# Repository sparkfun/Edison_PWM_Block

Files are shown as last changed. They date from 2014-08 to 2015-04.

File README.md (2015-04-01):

SparkFun Edison PWM Block
==================================================

SparkFun Edison PWM Block

[*SparkFun Edison PWM Block(DEV-13042)*](https://www.sparkfun.com/products/13042)

This card adds eight channels of PWM control to the Edison's I<sup>2</sup>C bus. While the PWM output can be used for any generic PWM application, it is specifically intended to provide drive control for up to eight standard hobby-type servo motors. To that end, it has an independent input for supply voltage for the servos above the normal range of the Edison, and 8 connections that support the most common pinout of hobby servo motors.

The PCA9685 provides open-collector or push-pull output capabilities; as the intended target is servo motors, the board has a pull-up resistor to the independently connected servo supply voltage. The PCA9685 has an independent clock that can be operated at 50Hz, for servo control; at that frequency, the 12-bit resolution of the device provides approximately 200 steps of resolution for a servo motor.

The PCA9685 can be used as an open collector current driver for LEDs up to 25mA as well. Six solder jumpers allow the user to attach up to 63 of these cards to a single Edison, or to adjust the address of the PCA9685 to avoid collision with other addresses on the bus.

Repository Contents
-------------------
* **/Hardware** - All Eagle design files (.brd, .sch)
* **/Production** - Test bed files and production panel files

License Information
-------------------
The hardware is released under [Creative Commons ShareAlike 4.0 International](https://creativecommons.org/licenses/by-sa/4.0/).
The code is beerware; if you see me (or any other SparkFun employee) at the local, and you've found our code helpful, please buy us a round!

Distributed as-is; no warranty is given.

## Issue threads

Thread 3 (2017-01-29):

I2C not Working

Luchta, 2017-01-29:
I got the following error code after trying to get the sample code to work:

"terminate called after throwing an instance of 'std::invalid_argument'
what(): Unknown error in I2c::readReg()"

I found the Error in the Constructor of pca9685.
Fabulous Idea to set the prescaler and let it read registers, before setting the address.
changing the order of those two fixed the error.

mhord, 2017-01-30:
Please provide more information. There's no code at all in this repository, and the constructor for the pca9685 class in the library we wrote for the block doesn't access anything before setting the address. I'm looking at [this repository](https://github.com/sparkfun/SparkFun_PWM_Block_for_Edison_CPP_Library) for the code. Is there a code example elsewhere that doesn't initialize things in the right order?

Luchta, 2017-01-30:
Hey there,

I am talking about this part:

// Constructor. Pretty self explanatory.
pca9685::pca9685(mraa::I2c* pca_port, uint8_t myI2CAddress):
   _pca_port(pca_port), _myAddress(myI2CAddress),
   _minServoPL(MIN_WIDTH), _maxServoPL(MAX_WIDTH),
   _minAngle(0), _maxAngle(180)
{
   setPrescaler(14); // f= ~400Hz
   _pca_port->address(_myAddress);
   _pca_port->writeReg(MODE1, AI); //enable autoincrement and osc
   _pca_port->writeReg(MODE2, INVRT); // open drain outs
}

the address is written in "_pca_port->address(_myAddress);"

however, "setPrescaler(14);" already accesses the bus and created the
error I mentioned.

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

mhord, 2017-01-30:
Got it. Thanks for the tip!

Closed 2017-01-30.

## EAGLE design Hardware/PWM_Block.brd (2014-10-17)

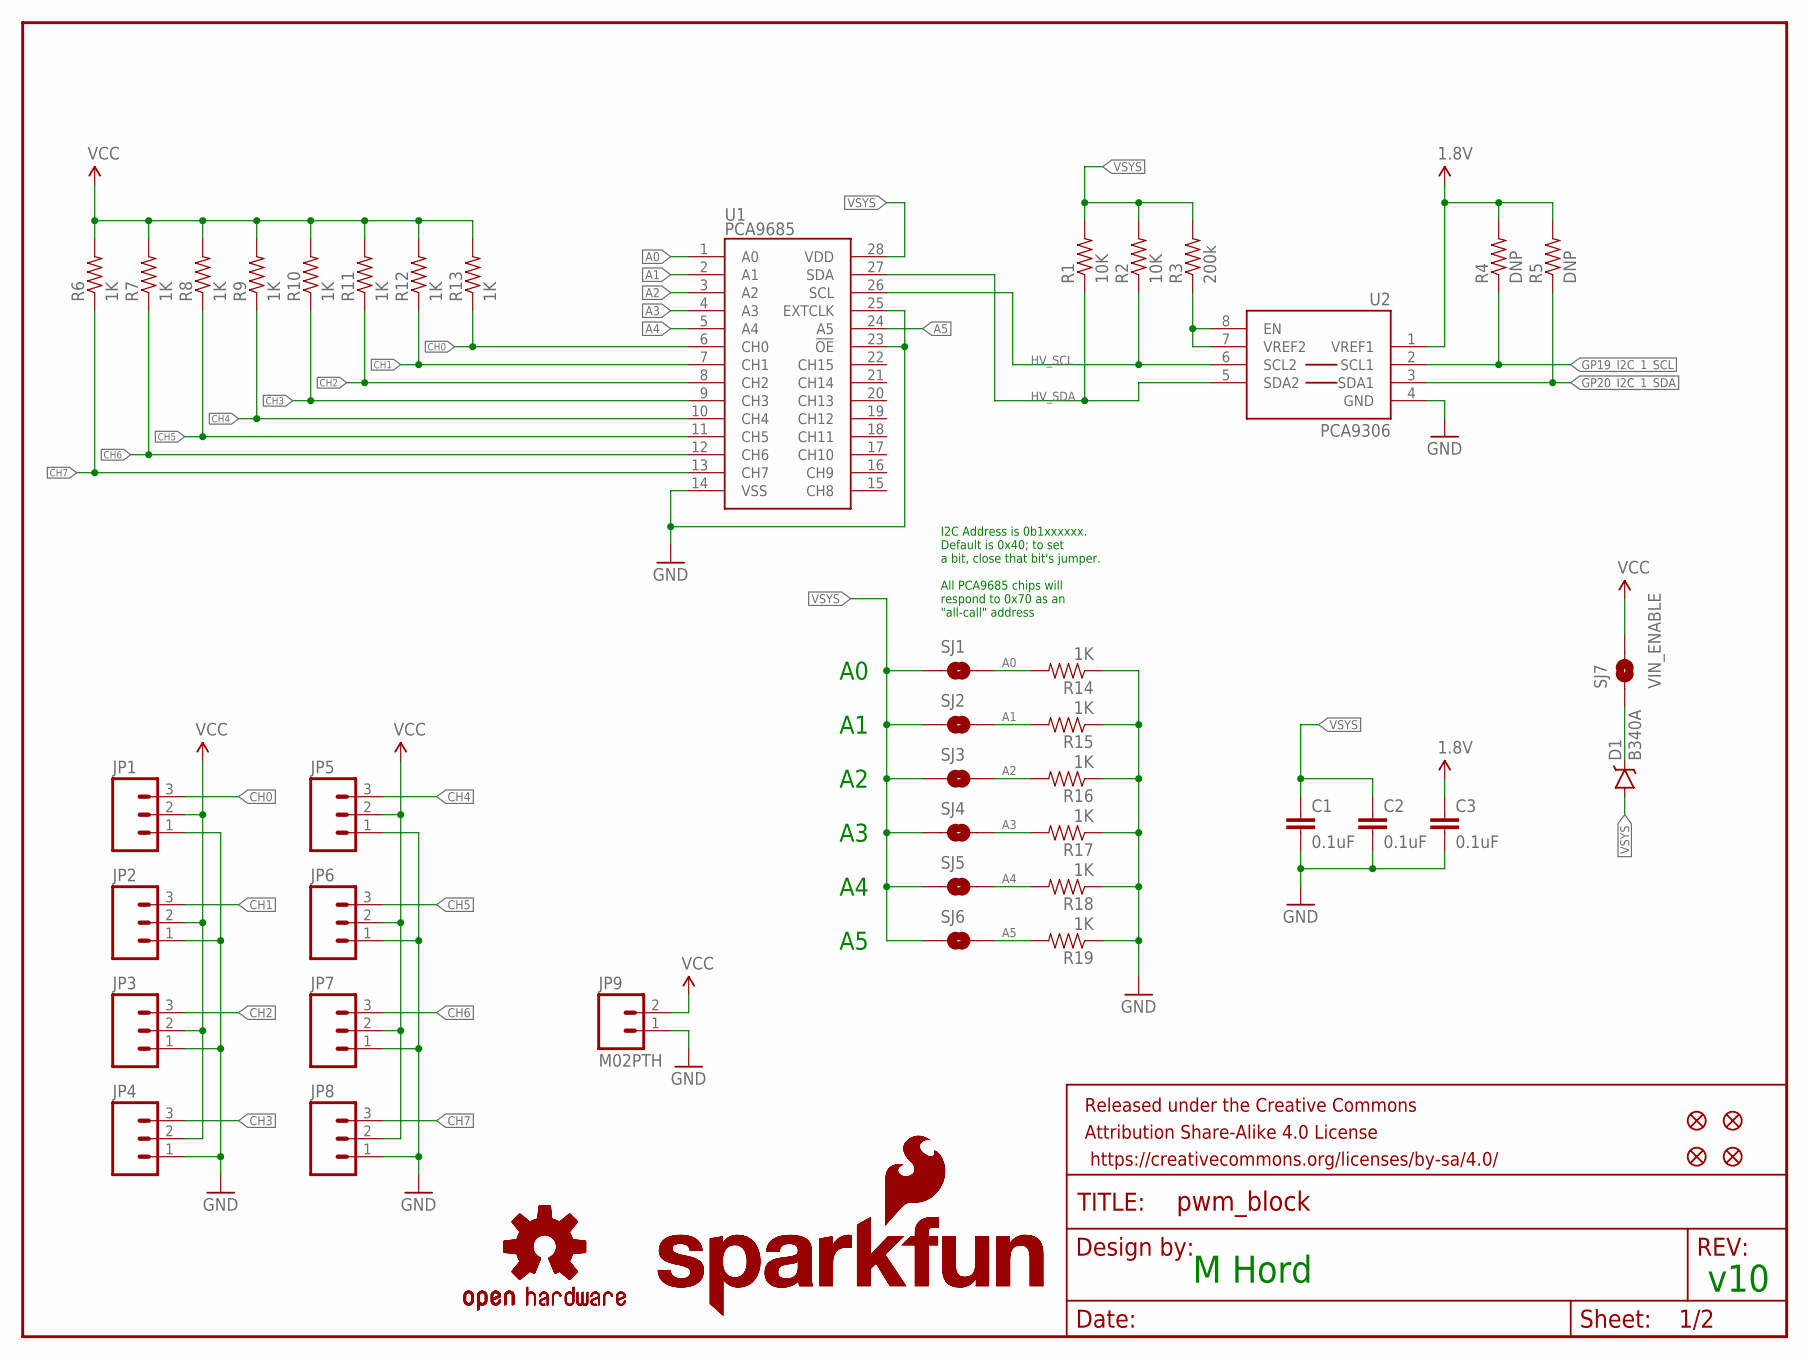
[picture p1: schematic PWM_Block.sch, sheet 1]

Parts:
C1, C2, C3: 0.1uF; 0603-CAP
D1: B340A; SMA-DIODE
FID1, FID2, FID3, FID4: FIDUCIAL1X2; FIDUCIAL-1X2
FRAME1: FRAME-LETTER; CREATIVE_COMMONS
JP1, JP2, JP3, JP4, JP5, JP6, JP7, JP8: M03PTH; 1X03
JP9: M02PTH; 1X02
LOGO1, LOGO3: SFE_LOGO_NAME_FLAME.1_INCH; SFE_LOGO_NAME_FLAME_.1
LOGO2, LOGO4: OSHW-LOGOS; OSHW-LOGO-S
R1, R2: 10K; 0603-RES
R3: 200k; 0603-RES
R4, R5: DNP; 0603-RES
R6, R7, R8, R9, R10, R11, R12, R13, R14, R15, R16, R17, R18, R19: 1K; 0603-RES
SJ1, SJ2, SJ3, SJ4, SJ5, SJ6: JUMPER-PAD-2-NOYES_SILK; PAD-JUMPER-2-NO_YES_SILK
SJ7: VIN_ENABLE; PAD-JUMPER-2-NO_YES_SILK
U1: PCA9685; TSSOP-28_4MM
U2: PCA9306; PCA9306DC-1:1

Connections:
1.8V: C3.1, R4.2, R5.2, U2.1 (VREF1); also elsewhere on the board
A0: R14.2, SJ1.2, U1.1 (A0)
A1: R15.2, SJ2.2, U1.2 (A1)
A2: R16.2, SJ3.2, U1.3 (A2)
A3: R17.2, SJ4.2, U1.4 (A3)
A4: R18.2, SJ5.2, U1.5 (A4)
A5: R19.2, SJ6.2, U1.24 (A5)
CH0: JP1.3, R13.1, U1.6 (CH0)
CH1: JP2.3, R12.1, U1.7 (CH1)
CH2: JP3.3, R11.1, U1.8 (CH2)
CH3: JP4.3, R10.1, U1.9 (CH3)
CH4: JP5.3, R9.1, U1.10 (CH4)
CH5: JP6.3, R8.1, U1.11 (CH5)
CH6: JP7.3, R7.1, U1.12 (CH6)
CH7: JP8.3, R6.1, U1.13 (CH7)
GND: C1.2, C2.2, C3.2, JP1.1, JP2.1, JP3.1, JP4.1, JP5.1, JP6.1, JP7.1, JP8.1, JP9.1, R14.1, R15.1, R16.1, R17.1, R18.1, R19.1, U1.14 (VSS), U1.23 (!OE), U1.25 (EXTCLK), U2.4 (GND); also elsewhere on the board
GP19_I2C_1_SCL: R4.1, U2.2 (SCL1); also elsewhere on the board
GP20_I2C_1_SDA: R5.1, U2.3 (SDA1); also elsewhere on the board
HV_SCL: R2.1, U1.26 (SCL), U2.6 (SCL2)
HV_SDA: R1.1, U1.27 (SDA), U2.5 (SDA2)
unnamed: R3.1, U2.7 (VREF2), U2.8 (EN)
unnamed: D1.C, SJ7.1
VCC: JP1.2, JP2.2, JP3.2, JP4.2, JP5.2, JP6.2, JP7.2, JP8.2, JP9.2, R6.2, R7.2, R8.2, R9.2, R10.2, R11.2, R12.2, R13.2, SJ7.2
VSYS: C1.1, C2.1, D1.A, R1.2, R2.2, R3.2, SJ1.1, SJ2.1, SJ3.1, SJ4.1, SJ5.1, SJ6.1, U1.28 (VDD); also elsewhere on the board

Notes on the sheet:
M Hord
v10
I2C Address is 0b1xxxxxx. Default is 0x40; to set a bit, close that bit's jumper. All PCA9685 chips will respond to 0x70 as an "all-call" address

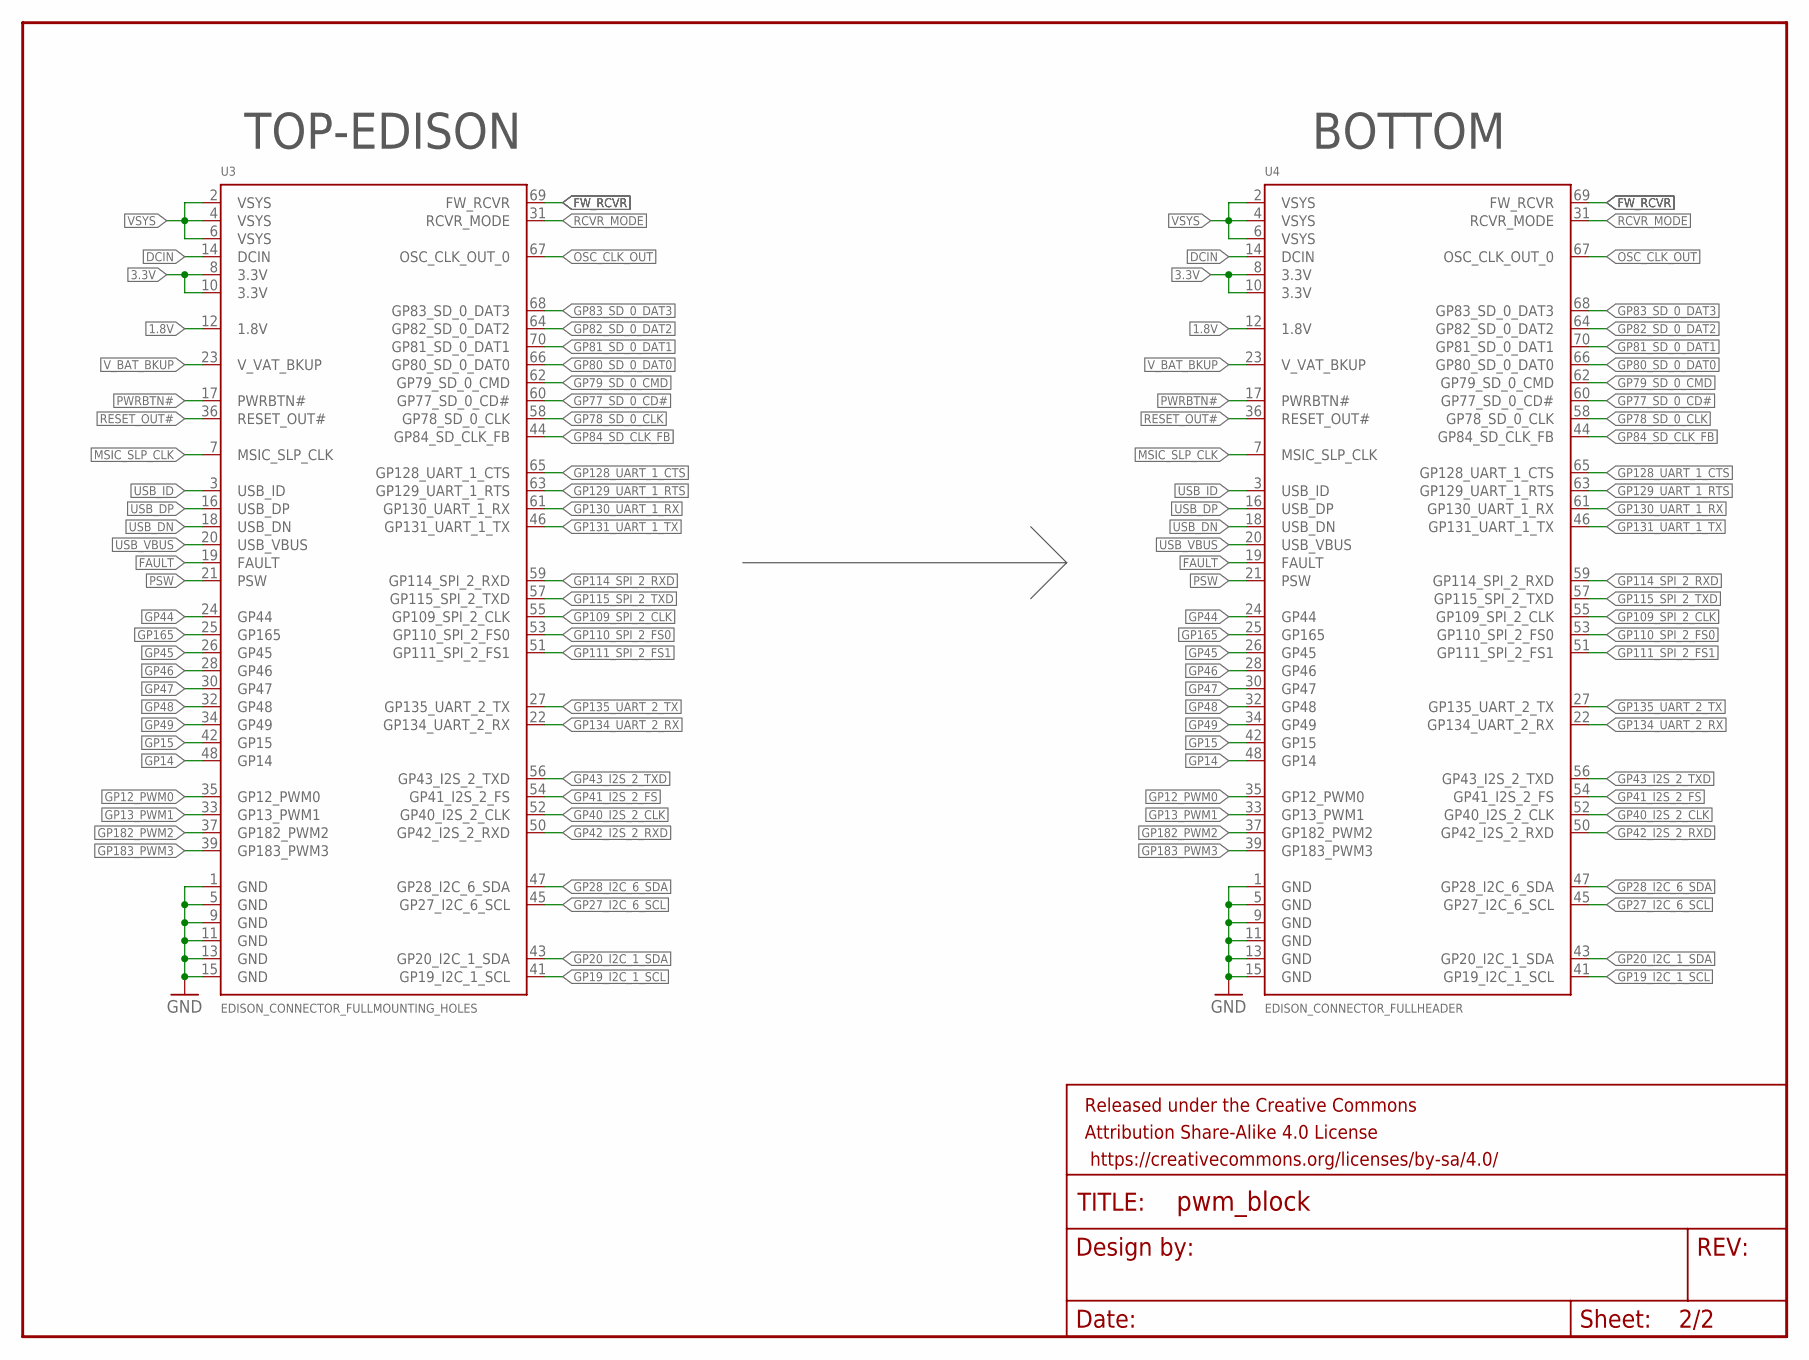
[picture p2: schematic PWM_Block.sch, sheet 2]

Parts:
FRAME2: FRAME-LETTER; CREATIVE_COMMONS
U3: EDISON_CONNECTOR_FULLMOUNTING_HOLES; EDISON_DAUGHTER
U4: EDISON_CONNECTOR_FULLHEADER; DF40C-70DP-0.4(51)

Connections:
1.8V: U3.12 (1.8V), U4.12 (1.8V); also elsewhere on the board
3.3V: U3.8 (3.3V), U3.10 (3.3V), U4.8 (3.3V), U4.10 (3.3V)
DCIN: U3.14 (DCIN), U4.14 (DCIN)
FAULT: U3.19 (FAULT), U4.19 (FAULT)
FW_RCVR: U3.69 (FW_RCVR), U4.69 (FW_RCVR)
GND: U3.1 (GND), U3.5 (GND), U3.9 (GND), U3.11 (GND), U3.13 (GND), U3.15 (GND), U4.1 (GND), U4.5 (GND), U4.9 (GND), U4.11 (GND), U4.13 (GND), U4.15 (GND); also elsewhere on the board
GP12_PWM0: U3.35 (GP12_PWM0), U4.35 (GP12_PWM0)
GP13_PWM1: U3.33 (GP13_PWM1), U4.33 (GP13_PWM1)
GP14: U3.48 (GP14), U4.48 (GP14)
GP15: U3.42 (GP15), U4.42 (GP15)
GP19_I2C_1_SCL: U3.41 (GP19_I2C_1_SCL), U4.41 (GP19_I2C_1_SCL); also elsewhere on the board
GP20_I2C_1_SDA: U3.43 (GP20_I2C_1_SDA), U4.43 (GP20_I2C_1_SDA); also elsewhere on the board
GP27_I2C_6_SCL: U3.45 (GP27_I2C_6_SCL), U4.45 (GP27_I2C_6_SCL)
GP28_I2C_6_SDA: U3.47 (GP28_I2C_6_SDA), U4.47 (GP28_I2C_6_SDA)
GP40_I2S_2_CLK: U3.52 (GP40_I2S_2_CLK), U4.52 (GP40_I2S_2_CLK)
GP41_I2S_2_FS: U3.54 (GP41_I2S_2_FS), U4.54 (GP41_I2S_2_FS)
GP42_I2S_2_RXD: U3.50 (GP42_I2S_2_RXD), U4.50 (GP42_I2S_2_RXD)
GP43_I2S_2_TXD: U3.56 (GP43_I2S_2_TXD), U4.56 (GP43_I2S_2_TXD)
GP44: U3.24 (GP44), U4.24 (GP44)
GP45: U3.26 (GP45), U4.26 (GP45)
GP46: U3.28 (GP46), U4.28 (GP46)
GP47: U3.30 (GP47), U4.30 (GP47)
GP48: U3.32 (GP48), U4.32 (GP48)
GP49: U3.34 (GP49), U4.34 (GP49)
GP77_SD_0_CD#: U3.60 (GP77_SD_0_CD#), U4.60 (GP77_SD_0_CD#)
GP78_SD_0_CLK: U3.58 (GP78_SD_0_CLK), U4.58 (GP78_SD_0_CLK)
GP79_SD_0_CMD: U3.62 (GP79_SD_0_CMD), U4.62 (GP79_SD_0_CMD)
GP80_SD_0_DAT0: U3.66 (GP80_SD_0_DAT0), U4.66 (GP80_SD_0_DAT0)
GP81_SD_0_DAT1: U3.70 (GP81_SD_0_DAT1), U4.70 (GP81_SD_0_DAT1)
GP82_SD_0_DAT2: U3.64 (GP82_SD_0_DAT2), U4.64 (GP82_SD_0_DAT2)
GP83_SD_0_DAT3: U3.68 (GP83_SD_0_DAT3), U4.68 (GP83_SD_0_DAT3)
GP84_SD_CLK_FB: U3.44 (GP84_SD_CLK_FB), U4.44 (GP84_SD_CLK_FB)
GP109_SPI_2_CLK: U3.55 (GP109_SPI_2_CLK), U4.55 (GP109_SPI_2_CLK)
GP110_SPI_2_FS0: U3.53 (GP110_SPI_2_FS0), U4.53 (GP110_SPI_2_FS0)
GP111_SPI_2_FS1: U3.51 (GP111_SPI_2_FS1), U4.51 (GP111_SPI_2_FS1)
GP114_SPI_2_RXD: U3.59 (GP114_SPI_2_RXD), U4.59 (GP114_SPI_2_RXD)
GP115_SPI_2_TXD: U3.57 (GP115_SPI_2_TXD), U4.57 (GP115_SPI_2_TXD)
GP128_UART_1_CTS: U3.65 (GP128_UART_1_CTS), U4.65 (GP128_UART_1_CTS)
GP129_UART_1_RTS: U3.63 (GP129_UART_1_RTS), U4.63 (GP129_UART_1_RTS)
GP130_UART_1_RX: U3.61 (GP130_UART_1_RX), U4.61 (GP130_UART_1_RX)
GP131_UART_1_TX: U3.46 (GP131_UART_1_TX), U4.46 (GP131_UART_1_TX)
GP134_UART_2_RX: U3.22 (GP134_UART_2_RX), U4.22 (GP134_UART_2_RX)
GP135_UART_2_TX: U3.27 (GP135_UART_2_TX), U4.27 (GP135_UART_2_TX)
GP165: U3.25 (GP165), U4.25 (GP165)
GP182_PWM2: U3.37 (GP182_PWM2), U4.37 (GP182_PWM2)
GP183_PWM3: U3.39 (GP183_PWM3), U4.39 (GP183_PWM3)
MSIC_SLP_CLK: U3.7 (MSIC_SLP_CLK), U4.7 (MSIC_SLP_CLK)
OSC_CLK_OUT: U3.67 (OSC_CLK_OUT_0), U4.67 (OSC_CLK_OUT_0)
PSW: U3.21 (PSW), U4.21 (PSW)
PWRBTN#: U3.17 (PWRBTN#), U4.17 (PWRBTN#)
RCVR_MODE: U3.31 (RCVR_MODE), U4.31 (RCVR_MODE)
RESET_OUT#: U3.36 (RESET_OUT#), U4.36 (RESET_OUT#)
USB_DN: U3.18 (USB_DN), U4.18 (USB_DN)
USB_DP: U3.16 (USB_DP), U4.16 (USB_DP)
USB_ID: U3.3 (USB_ID), U4.3 (USB_ID)
USB_VBUS: U3.20 (USB_VBUS), U4.20 (USB_VBUS)
VSYS: U3.2 (VSYS), U3.4 (VSYS), U3.6 (VSYS), U4.2 (VSYS), U4.4 (VSYS), U4.6 (VSYS); also elsewhere on the board
V_BAT_BKUP: U3.23 (V_VAT_BKUP), U4.23 (V_VAT_BKUP)

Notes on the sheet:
TOP-EDISON
BOTTOM

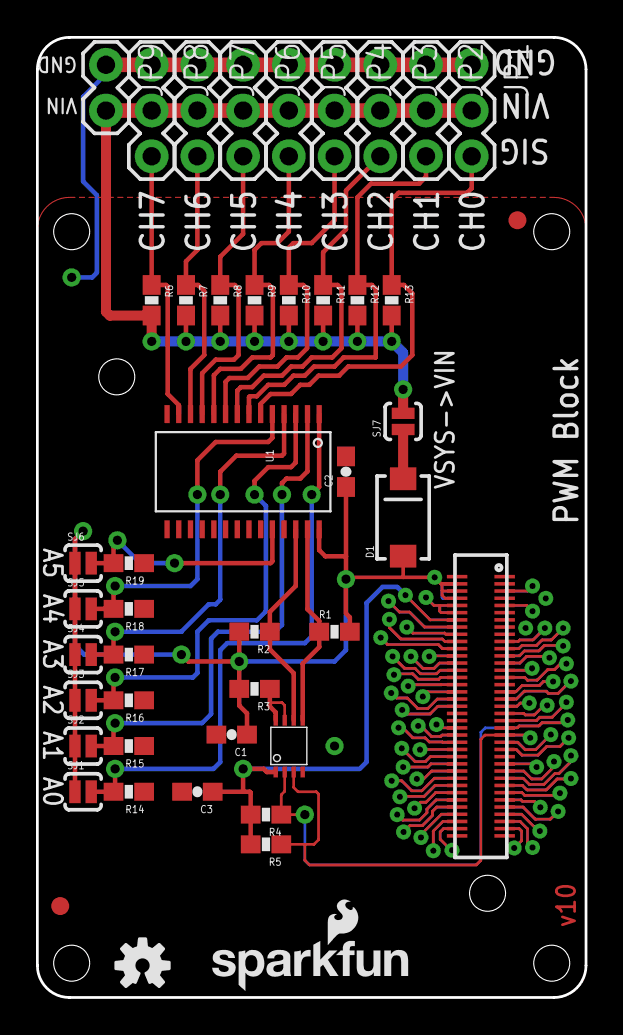
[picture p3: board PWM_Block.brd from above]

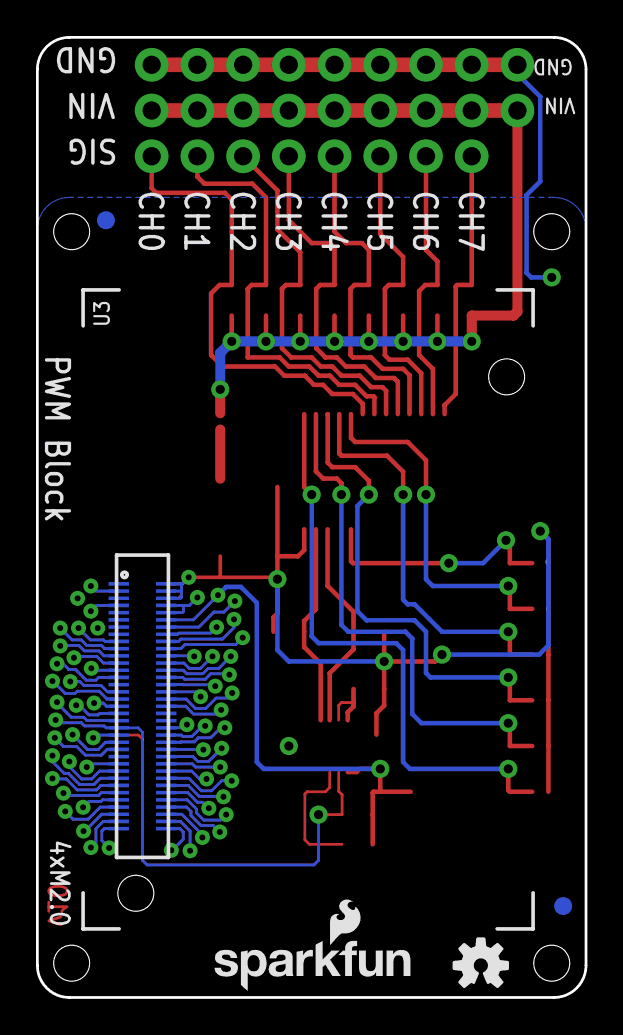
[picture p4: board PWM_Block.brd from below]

Board: 2 copper layers, 30.5 x 53.3 mm, 53 parts (6 on the bottom side), 77 nets.

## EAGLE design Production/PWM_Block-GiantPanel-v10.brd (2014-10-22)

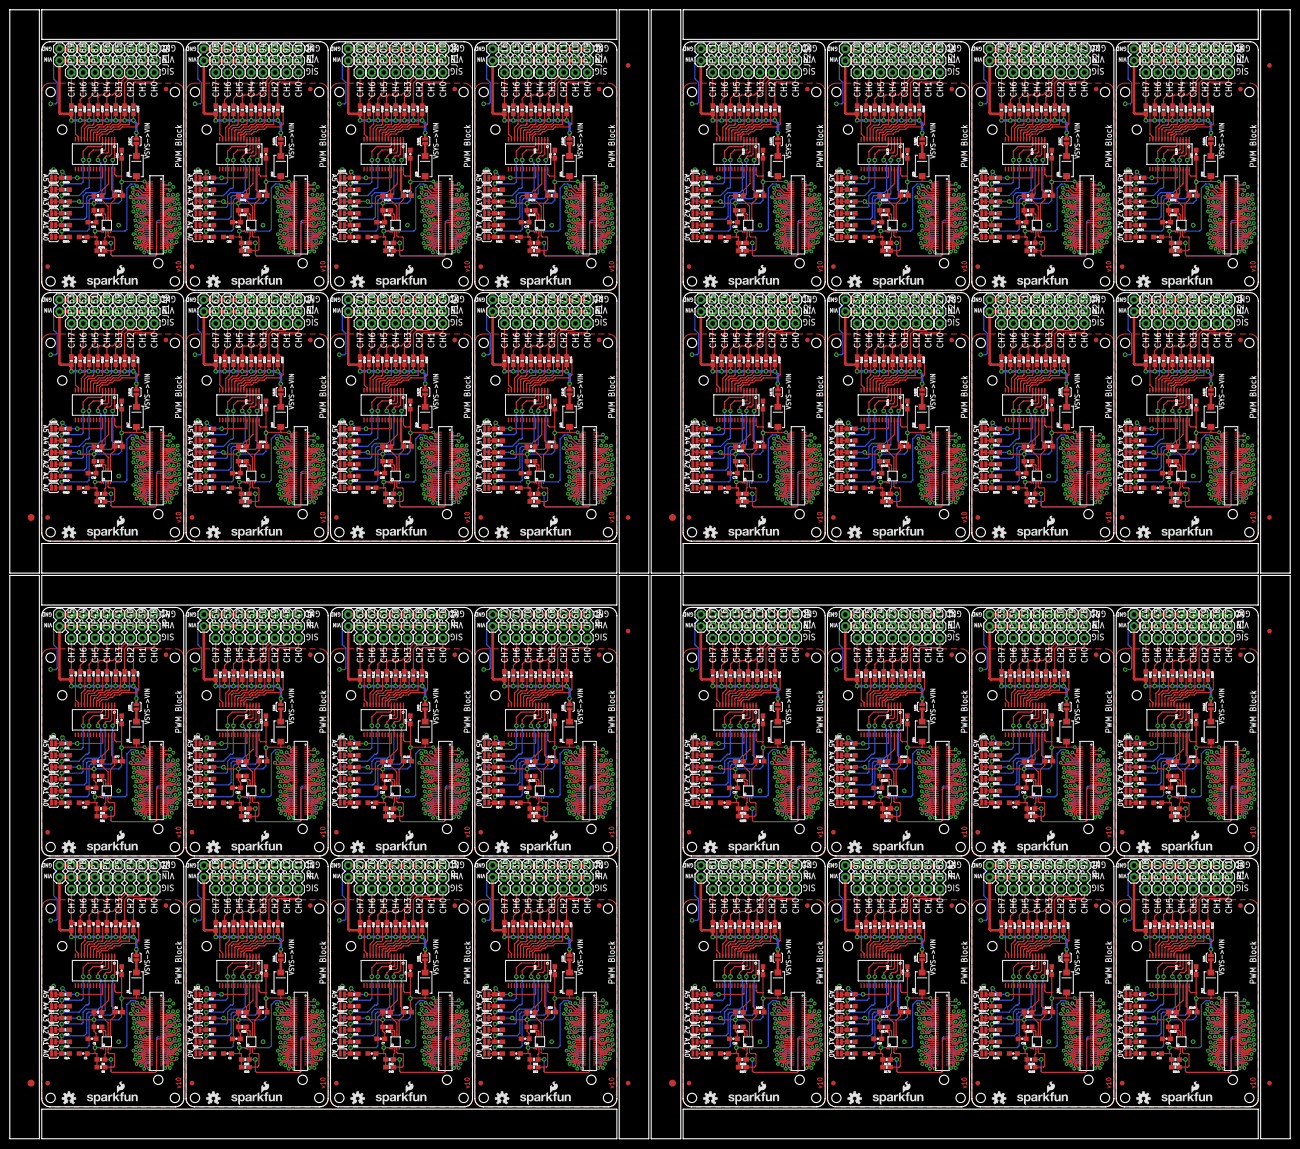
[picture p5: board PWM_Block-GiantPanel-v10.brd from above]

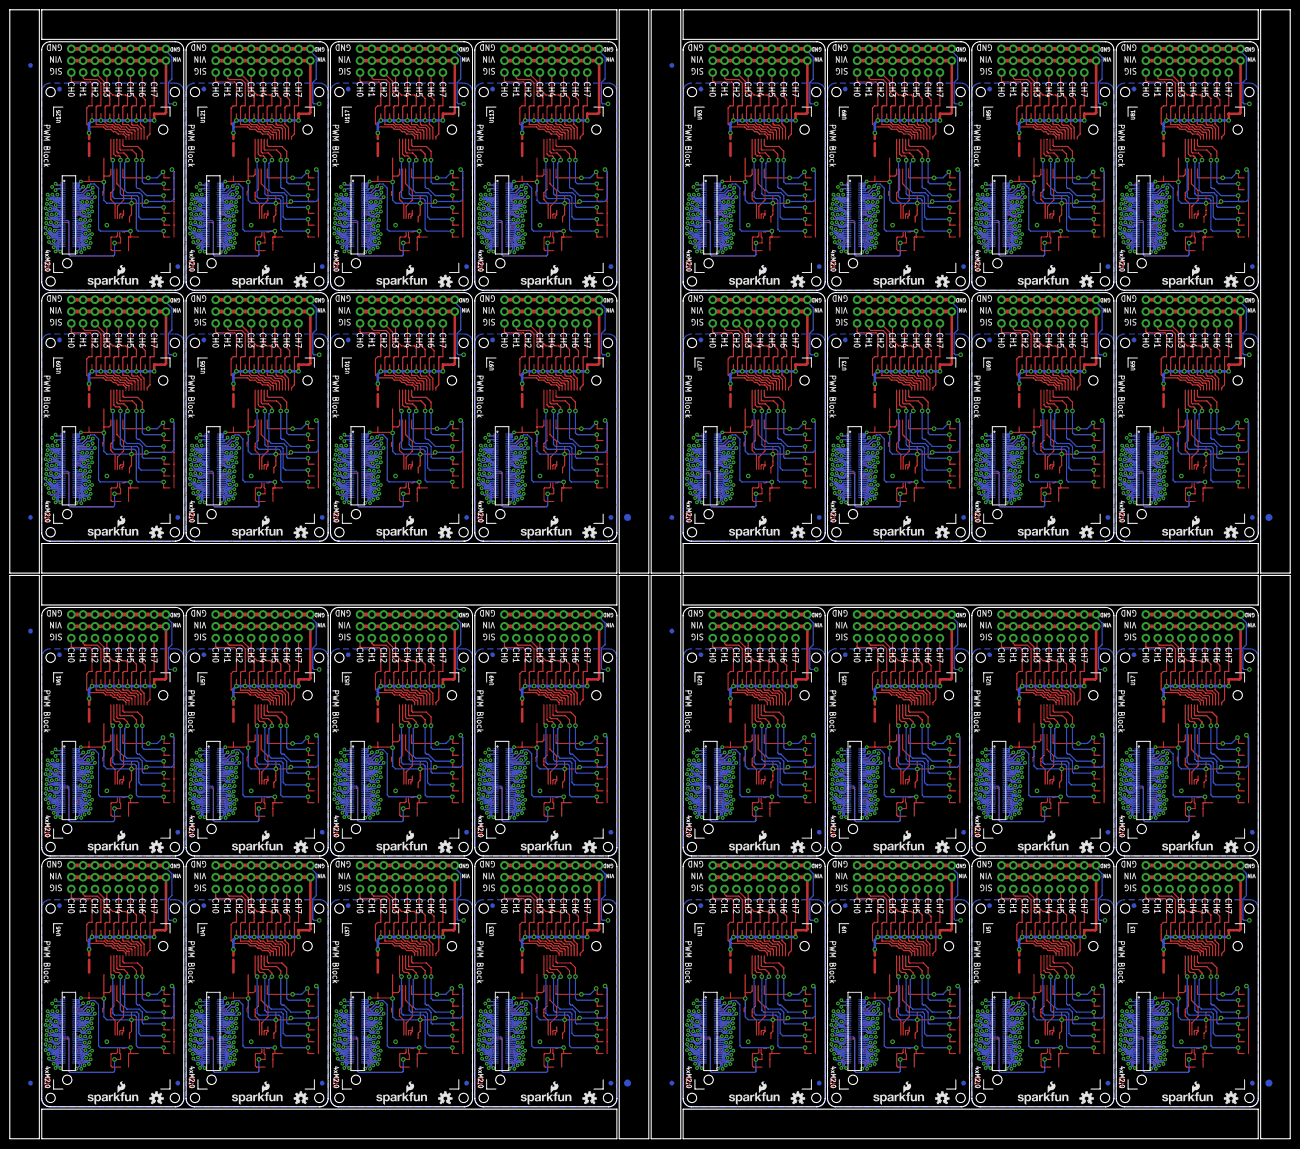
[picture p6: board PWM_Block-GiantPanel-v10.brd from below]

Board: 2 copper layers, 274.8 x 242.3 mm, 1656 parts (204 on the bottom side), 2464 nets.

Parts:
C1, C2, C3, C4, C5, C6, C7, C8, C9, C10, C11, C12, C13, C14, C15, C16, C17, C18, C19, C20, C21, C22, C23, C24, C25, C26, C27, C28, C29, C30, C31, C32, C33, C34, C35, C36, C37, C38, C39, C40, C41, C42, C43, C44, C45, C46, C47, C48, C49, C50, C51, C52, C53, C54, C55, C56, C57, C58, C59, C60, C61, C62, C63, C64, C65, C66, C67, C68, C69, C70, C71, C72, C73, C74, C75, C76, C77, C78, C79, C80, C81, C82, C83, C84, C85, C86, C87, C88, C89, C90, C91, C92, C93, C94, C95, C96: 0.1uF; 0603-CAP
D1, D2, D3, D4, D5, D6, D7, D8, D9, D10, D11, D12, D13, D14, D15, D16, D17, D18, D19, D20, D21, D22, D23, D24, D25, D26, D27, D28, D29, D30, D31, D32: B340A; SMA-DIODE
E$1, E$2, E$9, E$10, E$15, E$16, E$21, E$22: FIDUCIAL-1.5X3
E$3, E$4, E$5, E$6, E$7, E$8, E$11, E$12, E$13, E$14, E$17, E$18, E$19, E$20, E$23, E$24: FIDUCIAL-1X2
FID1, FID2, FID3, FID4, FID5, FID6, FID7, FID8, FID9, FID10, FID11, FID12, FID13, FID14, FID15, FID16, FID17, FID18, FID19, FID20, FID21, FID22, FID23, FID24, FID25, FID26, FID27, FID28, FID29, FID30, FID31, FID32, FID33, FID34, FID35, FID36, FID37, FID38, FID39, FID40, FID41, FID42, FID43, FID44, FID45, FID46, FID47, FID48, FID49, FID50, FID51, FID52, FID53, FID54, FID55, FID56, FID57, FID58, FID59, FID60, FID61, FID62, FID63, FID64, FID65, FID66, FID67, FID68, FID69, FID70, FID71, FID72, FID73, FID74, FID75, FID76, FID77, FID78, FID79, FID80, FID81, FID82, FID83, FID84, FID85, FID86, FID87, FID88, FID89, FID90, FID91, FID92, FID93, FID94, FID95, FID96, FID97, FID98, FID99, FID100, FID101, FID102, FID103, FID104, FID105, FID106, FID107, FID108, FID109, FID110, FID111, FID112, FID113, FID114, FID115, FID116, FID117, FID118, FID119, FID120, FID121, FID122, FID123, FID124, FID125, FID126, FID127, FID128: FIDUCIAL1X2; FIDUCIAL-1X2
JP1, JP2, JP3, JP4, JP5, JP6, JP7, JP8, JP10, JP11, JP12, JP13, JP14, JP15, JP16, JP17, JP19, JP20, JP21, JP22, JP23, JP24, JP25, JP26, JP28, JP29, JP30, JP31, JP32, JP33, JP34, JP35, JP37, JP38, JP39, JP40, JP41, JP42, JP43, JP44, JP46, JP47, JP48, JP49, JP50, JP51, JP52, JP53, JP55, JP56, JP57, JP58, JP59, JP60, JP61, JP62, JP64, JP65, JP66, JP67, JP68, JP69, JP70, JP71, JP73, JP74, JP75, JP76, JP77, JP78, JP79, JP80, JP82, JP83, JP84, JP85, JP86, JP87, JP88, JP89, JP91, JP92, JP93, JP94, JP95, JP96, JP97, JP98, JP100, JP101, JP102, JP103, JP104, JP105, JP106, JP107, JP109, JP110, JP111, JP112, JP113, JP114, JP115, JP116, JP118, JP119, JP120, JP121, JP122, JP123, JP124, JP125, JP127, JP128, JP129, JP130, JP131, JP132, JP133, JP134, JP136, JP137, JP138, JP139, JP140, JP141, JP142, JP143, JP145, JP146, JP147, JP148, JP149, JP150, JP151, JP152, JP154, JP155, JP156, JP157, JP158, JP159, JP160, JP161, JP163, JP164, JP165, JP166, JP167, JP168, JP169, JP170, JP172, JP173, JP174, JP175, JP176, JP177, JP178, JP179, JP181, JP182, JP183, JP184, JP185, JP186, JP187, JP188, JP190, JP191, JP192, JP193, JP194, JP195, JP196, JP197, JP199, JP200, JP201, JP202, JP203, JP204, JP205, JP206, JP208, JP209, JP210, JP211, JP212, JP213, JP214, JP215, JP217, JP218, JP219, JP220, JP221, JP222, JP223, JP224, JP226, JP227, JP228, JP229, JP230, JP231, JP232, JP233, JP235, JP236, JP237, JP238, JP239, JP240, JP241, JP242, JP244, JP245, JP246, JP247, JP248, JP249, JP250, JP251, JP253, JP254, JP255, JP256, JP257, JP258, JP259, JP260, JP262, JP263, JP264, JP265, JP266, JP267, JP268, JP269, JP271, JP272, JP273, JP274, JP275, JP276, JP277, JP278, JP280, JP281, JP282, JP283, JP284, JP285, JP286, JP287: 1X03
JP9, JP18, JP27, JP36, JP45, JP54, JP63, JP72, JP81, JP90, JP99, JP108, JP117, JP126, JP135, JP144, JP153, JP162, JP171, JP180, JP189, JP198, JP207, JP216, JP225, JP234, JP243, JP252, JP261, JP270, JP279, JP288: M02PTH; 1X02
LOGO1, LOGO3, LOGO6, LOGO7, LOGO10, LOGO11, LOGO14, LOGO15, LOGO18, LOGO19, LOGO22, LOGO23, LOGO26, LOGO27, LOGO30, LOGO31, LOGO34, LOGO35, LOGO38, LOGO39, LOGO42, LOGO43, LOGO46, LOGO47, LOGO50, LOGO51, LOGO54, LOGO55, LOGO58, LOGO59, LOGO62, LOGO63, LOGO66, LOGO67, LOGO70, LOGO71, LOGO74, LOGO75, LOGO78, LOGO79, LOGO82, LOGO83, LOGO86, LOGO87, LOGO90, LOGO91, LOGO94, LOGO95, LOGO98, LOGO99, LOGO102, LOGO103, LOGO106, LOGO107, LOGO110, LOGO111, LOGO114, LOGO115, LOGO118, LOGO119, LOGO122, LOGO123, LOGO126, LOGO127: SFE_LOGO_NAME_FLAME.1_INCH; SFE_LOGO_NAME_FLAME_.1
LOGO2, LOGO4, LOGO5, LOGO8, LOGO9, LOGO12, LOGO13, LOGO16, LOGO17, LOGO20, LOGO21, LOGO24, LOGO25, LOGO28, LOGO29, LOGO32, LOGO33, LOGO36, LOGO37, LOGO40, LOGO41, LOGO44, LOGO45, LOGO48, LOGO49, LOGO52, LOGO53, LOGO56, LOGO57, LOGO60, LOGO61, LOGO64, LOGO65, LOGO68, LOGO69, LOGO72, LOGO73, LOGO76, LOGO77, LOGO80, LOGO81, LOGO84, LOGO85, LOGO88, LOGO89, LOGO92, LOGO93, LOGO96, LOGO97, LOGO100, LOGO101, LOGO104, LOGO105, LOGO108, LOGO109, LOGO112, LOGO113, LOGO116, LOGO117, LOGO120, LOGO121, LOGO124, LOGO125, LOGO128: OSHW-LOGOS; OSHW-LOGO-S
R1, R2, R20, R21, R39, R40, R58, R59, R77, R78, R96, R97, R115, R116, R134, R135, R153, R154, R172, R173, R191, R192, R210, R211, R229, R230, R248, R249, R267, R268, R286, R287, R305, R306, R324, R325, R343, R344, R362, R363, R381, R382, R400, R401, R419, R420, R438, R439, R457, R458, R476, R477, R495, R496, R514, R515, R533, R534, R552, R553, R571, R572, R590, R591: 10K; 0603-RES
R3, R22, R41, R60, R79, R98, R117, R136, R155, R174, R193, R212, R231, R250, R269, R288, R307, R326, R345, R364, R383, R402, R421, R440, R459, R478, R497, R516, R535, R554, R573, R592: 200k; 0603-RES
R4, R5, R23, R24, R42, R43, R61, R62, R80, R81, R99, R100, R118, R119, R137, R138, R156, R157, R175, R176, R194, R195, R213, R214, R232, R233, R251, R252, R270, R271, R289, R290, R308, R309, R327, R328, R346, R347, R365, R366, R384, R385, R403, R404, R422, R423, R441, R442, R460, R461, R479, R480, R498, R499, R517, R518, R536, R537, R555, R556, R574, R575, R593, R594: DNP; 0603-RES
R6, R7, R8, R9, R10, R11, R12, R13, R14, R15, R16, R17, R18, R19, R25, R26, R27, R28, R29, R30, R31, R32, R33, R34, R35, R36, R37, R38, R44, R45, R46, R47, R48, R49, R50, R51, R52, R53, R54, R55, R56, R57, R63, R64, R65, R66, R67, R68, R69, R70, R71, R72, R73, R74, R75, R76, R82, R83, R84, R85, R86, R87, R88, R89, R90, R91, R92, R93, R94, R95, R101, R102, R103, R104, R105, R106, R107, R108, R109, R110, R111, R112, R113, R114, R120, R121, R122, R123, R124, R125, R126, R127, R128, R129, R130, R131, R132, R133, R139, R140, R141, R142, R143, R144, R145, R146, R147, R148, R149, R150, R151, R152, R158, R159, R160, R161, R162, R163, R164, R165, R166, R167, R168, R169, R170, R171, R177, R178, R179, R180, R181, R182, R183, R184, R185, R186, R187, R188, R189, R190, R196, R197, R198, R199, R200, R201, R202, R203, R204, R205, R206, R207, R208, R209, R215, R216, R217, R218, R219, R220, R221, R222, R223, R224, R225, R226, R227, R228, R234, R235, R236, R237, R238, R239, R240, R241, R242, R243, R244, R245, R246, R247, R253, R254, R255, R256, R257, R258, R259, R260, R261, R262, R263, R264, R265, R266, R272, R273, R274, R275, R276, R277, R278, R279, R280, R281, R282, R283, R284, R285, R291, R292, R293, R294, R295, R296, R297, R298, R299, R300, R301, R302, R303, R304, R310, R311, R312, R313, R314, R315, R316, R317, R318, R319, R320, R321, R322, R323, R329, R330, R331, R332, R333, R334, R335, R336, R337, R338, R339, R340, R341, R342, R348, R349, R350, R351, R352, R353, R354, R355, R356, R357, R358, R359, R360, R361, R367, R368, R369, R370, R371, R372, R373, R374, R375, R376, R377, R378, R379, R380, R386, R387, R388, R389, R390, R391, R392, R393, R394, R395, R396, R397, R398, R399, R405, R406, R407, R408, R409, R410, R411, R412, R413, R414, R415, R416, R417, R418, R424, R425, R426, R427, R428, R429, R430, R431, R432, R433, R434, R435, R436, R437, R443, R444, R445, R446, R447, R448, R449, R450, R451, R452, R453, R454, R455, R456, R462, R463, R464, R465, R466, R467, R468, R469, R470, R471, R472, R473, R474, R475, R481, R482, R483, R484, R485, R486, R487, R488, R489, R490, R491, R492, R493, R494, R500, R501, R502, R503, R504, R505, R506, R507, R508, R509, R510, R511, R512, R513, R519, R520, R521, R522, R523, R524, R525, R526, R527, R528, R529, R530, R531, R532, R538, R539, R540, R541, R542, R543, R544, R545, R546, R547, R548, R549, R550, R551, R557, R558, R559, R560, R561, R562, R563, R564, R565, R566, R567, R568, R569, R570, R576, R577, R578, R579, R580, R581, R582, R583, R584, R585, R586, R587, R588, R589, R595, R596, R597, R598, R599, R600, R601, R602, R603, R604, R605, R606, R607, R608: 1K; 0603-RES
SJ1, SJ2, SJ3, SJ4, SJ5, SJ6, SJ8, SJ9, SJ10, SJ11, SJ12, SJ13, SJ15, SJ16, SJ17, SJ18, SJ19, SJ20, SJ22, SJ23, SJ24, SJ25, SJ26, SJ27, SJ29, SJ30, SJ31, SJ32, SJ33, SJ34, SJ36, SJ37, SJ38, SJ39, SJ40, SJ41, SJ43, SJ44, SJ45, SJ46, SJ47, SJ48, SJ50, SJ51, SJ52, SJ53, SJ54, SJ55, SJ57, SJ58, SJ59, SJ60, SJ61, SJ62, SJ64, SJ65, SJ66, SJ67, SJ68, SJ69, SJ71, SJ72, SJ73, SJ74, SJ75, SJ76, SJ78, SJ79, SJ80, SJ81, SJ82, SJ83, SJ85, SJ86, SJ87, SJ88, SJ89, SJ90, SJ92, SJ93, SJ94, SJ95, SJ96, SJ97, SJ99, SJ100, SJ101, SJ102, SJ103, SJ104, SJ106, SJ107, SJ108, SJ109, SJ110, SJ111, SJ113, SJ114, SJ115, SJ116, SJ117, SJ118, SJ120, SJ121, SJ122, SJ123, SJ124, SJ125, SJ127, SJ128, SJ129, SJ130, SJ131, SJ132, SJ134, SJ135, SJ136, SJ137, SJ138, SJ139, SJ141, SJ142, SJ143, SJ144, SJ145, SJ146, SJ148, SJ149, SJ150, SJ151, SJ152, SJ153, SJ155, SJ156, SJ157, SJ158, SJ159, SJ160, SJ162, SJ163, SJ164, SJ165, SJ166, SJ167, SJ169, SJ170, SJ171, SJ172, SJ173, SJ174, SJ176, SJ177, SJ178, SJ179, SJ180, SJ181, SJ183, SJ184, SJ185, SJ186, SJ187, SJ188, SJ190, SJ191, SJ192, SJ193, SJ194, SJ195, SJ197, SJ198, SJ199, SJ200, SJ201, SJ202, SJ204, SJ205, SJ206, SJ207, SJ208, SJ209, SJ211, SJ212, SJ213, SJ214, SJ215, SJ216, SJ218, SJ219, SJ220, SJ221, SJ222, SJ223: JUMPER-PAD-2-NOYES_SILK; PAD-JUMPER-2-NO_YES_SILK
SJ7, SJ14, SJ21, SJ28, SJ35, SJ42, SJ49, SJ56, SJ63, SJ70, SJ77, SJ84, SJ91, SJ98, SJ105, SJ112, SJ119, SJ126, SJ133, SJ140, SJ147, SJ154, SJ161, SJ168, SJ175, SJ182, SJ189, SJ196, SJ203, SJ210, SJ217, SJ224: VIN_ENABLE; PAD-JUMPER-2-NO_YES_SILK
U1, U8, U12, U16, U20, U24, U28, U32, U36, U40, U44, U48, U52, U56, U60, U64, U68, U72, U76, U80, U84, U88, U92, U96, U100, U104, U108, U112, U116, U120, U124, U128: PCA9685; TSSOP-28_4MM
U2, U7, U11, U15, U19, U23, U27, U31, U35, U39, U43, U47, U51, U55, U59, U63, U67, U71, U75, U79, U83, U87, U91, U95, U99, U103, U107, U111, U115, U119, U123, U127: PCA9306; PCA9306DC-1:1
U3, U5, U9, U13, U17, U21, U25, U29, U33, U37, U41, U45, U49, U53, U57, U61, U65, U69, U73, U77, U81, U85, U89, U93, U97, U101, U105, U109, U113, U117, U121, U125: EDISON_CONNECTOR_FULLMOUNTING_HOLES; EDISON_DAUGHTER
U4, U6, U10, U14, U18, U22, U26, U30, U34, U38, U42, U46, U50, U54, U58, U62, U66, U70, U74, U78, U82, U86, U90, U94, U98, U102, U106, U110, U114, U118, U122, U126: EDISON_CONNECTOR_FULLHEADER; DF40C-70DP-0.4(51)

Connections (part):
1.8V: C3.1, R4.2, R5.2, U2.1, U3.12, U4.12
1.8V1: C6.1, R23.2, R24.2, U5.12, U6.12, U7.1
1.8V2: C9.1, R42.2, R43.2, U9.12, U10.12, U11.1
1.8V3: C12.1, R61.2, R62.2, U13.12, U14.12, U15.1
1.8V4: C15.1, R80.2, R81.2, U17.12, U18.12, U19.1
1.8V5: C18.1, R99.2, R100.2, U21.12, U22.12, U23.1
1.8V6: C21.1, R118.2, R119.2, U25.12, U26.12, U27.1
1.8V7: C24.1, R137.2, R138.2, U29.12, U30.12, U31.1
1.8V8: C27.1, R156.2, R157.2, U33.12, U34.12, U35.1
1.8V9: C30.1, R175.2, R176.2, U37.12, U38.12, U39.1
1.8V10: C33.1, R194.2, R195.2, U41.12, U42.12, U43.1
1.8V11: C36.1, R213.2, R214.2, U45.12, U46.12, U47.1
1.8V12: C39.1, R232.2, R233.2, U49.12, U50.12, U51.1
1.8V13: C42.1, R251.2, R252.2, U53.12, U54.12, U55.1
1.8V14: C45.1, R270.2, R271.2, U57.12, U58.12, U59.1
1.8V15: C48.1, R289.2, R290.2, U61.12, U62.12, U63.1
1.8V16: C51.1, R308.2, R309.2, U65.12, U66.12, U67.1
1.8V17: C54.1, R327.2, R328.2, U69.12, U70.12, U71.1
1.8V18: C57.1, R346.2, R347.2, U73.12, U74.12, U75.1
1.8V19: C60.1, R365.2, R366.2, U77.12, U78.12, U79.1
1.8V20: C63.1, R384.2, R385.2, U81.12, U82.12, U83.1
1.8V21: C66.1, R403.2, R404.2, U85.12, U86.12, U87.1
1.8V22: C69.1, R422.2, R423.2, U89.12, U90.12, U91.1
1.8V23: C72.1, R441.2, R442.2, U93.12, U94.12, U95.1
1.8V24: C75.1, R460.2, R461.2, U97.12, U98.12, U99.1
1.8V25: C78.1, R479.2, R480.2, U101.12, U102.12, U103.1
1.8V26: C81.1, R498.2, R499.2, U105.12, U106.12, U107.1
1.8V27: C84.1, R517.2, R518.2, U109.12, U110.12, U111.1
1.8V28: C87.1, R536.2, R537.2, U113.12, U114.12, U115.1
1.8V29: C90.1, R555.2, R556.2, U117.12, U118.12, U119.1
1.8V30: C93.1, R574.2, R575.2, U121.12, U122.12, U123.1
1.8V31: C96.1, R593.2, R594.2, U125.12, U126.12, U127.1
3.3V: U3.8, U3.10, U4.8, U4.10
3.3V1: U5.8, U5.10, U6.8, U6.10
3.3V2: U9.8, U9.10, U10.8, U10.10
3.3V3: U13.8, U13.10, U14.8, U14.10
3.3V4: U17.8, U17.10, U18.8, U18.10
3.3V5: U21.8, U21.10, U22.8, U22.10
3.3V6: U25.8, U25.10, U26.8, U26.10
3.3V7: U29.8, U29.10, U30.8, U30.10
3.3V8: U33.8, U33.10, U34.8, U34.10
3.3V9: U37.8, U37.10, U38.8, U38.10
3.3V10: U41.8, U41.10, U42.8, U42.10
3.3V11: U45.8, U45.10, U46.8, U46.10
3.3V12: U49.8, U49.10, U50.8, U50.10
3.3V13: U53.8, U53.10, U54.8, U54.10
3.3V14: U57.8, U57.10, U58.8, U58.10
3.3V15: U61.8, U61.10, U62.8, U62.10
3.3V16: U65.8, U65.10, U66.8, U66.10
3.3V17: U69.8, U69.10, U70.8, U70.10
3.3V18: U73.8, U73.10, U74.8, U74.10
3.3V19: U77.8, U77.10, U78.8, U78.10
3.3V20: U81.8, U81.10, U82.8, U82.10
3.3V21: U85.8, U85.10, U86.8, U86.10
3.3V22: U89.8, U89.10, U90.8, U90.10
3.3V23: U93.8, U93.10, U94.8, U94.10
3.3V24: U97.8, U97.10, U98.8, U98.10
3.3V25: U101.8, U101.10, U102.8, U102.10
3.3V26: U105.8, U105.10, U106.8, U106.10
3.3V27: U109.8, U109.10, U110.8, U110.10
3.3V28: U113.8, U113.10, U114.8, U114.10
3.3V29: U117.8, U117.10, U118.8, U118.10
3.3V30: U121.8, U121.10, U122.8, U122.10
3.3V31: U125.8, U125.10, U126.8, U126.10
A0: R14.2, SJ1.2, U1.1
A1: R15.2, SJ2.2, U1.2
A2: R16.2, SJ3.2, U1.3
A3: R17.2, SJ4.2, U1.4
A4: R18.2, SJ5.2, U1.5
A5: R19.2, SJ6.2, U1.24
A6: R37.2, SJ12.2, U8.5
A7: R36.2, SJ11.2, U8.4
A8: R35.2, SJ10.2, U8.3
A9: R34.2, SJ9.2, U8.2
A10: R33.2, SJ8.2, U8.1
A11: R38.2, SJ13.2, U8.24
A12: R56.2, SJ19.2, U12.5
A13: R55.2, SJ18.2, U12.4
A14: R54.2, SJ17.2, U12.3
A15: R53.2, SJ16.2, U12.2
A16: R52.2, SJ15.2, U12.1
A17: R57.2, SJ20.2, U12.24
A18: R75.2, SJ26.2, U16.5
A19: R74.2, SJ25.2, U16.4
A20: R73.2, SJ24.2, U16.3
A21: R72.2, SJ23.2, U16.2
A22: R71.2, SJ22.2, U16.1
A23: R76.2, SJ27.2, U16.24
A24: R94.2, SJ33.2, U20.5
A25: R93.2, SJ32.2, U20.4
A26: R92.2, SJ31.2, U20.3
A27: R91.2, SJ30.2, U20.2
A28: R90.2, SJ29.2, U20.1
A29: R95.2, SJ34.2, U20.24
A30: R113.2, SJ40.2, U24.5
A31: R112.2, SJ39.2, U24.4
A32: R111.2, SJ38.2, U24.3
A33: R110.2, SJ37.2, U24.2
A34: R109.2, SJ36.2, U24.1
A35: R114.2, SJ41.2, U24.24
A36: R132.2, SJ47.2, U28.5
A37: R131.2, SJ46.2, U28.4
A38: R130.2, SJ45.2, U28.3
A39: R129.2, SJ44.2, U28.2
A40: R128.2, SJ43.2, U28.1
A41: R133.2, SJ48.2, U28.24
A42: R151.2, SJ54.2, U32.5
A43: R150.2, SJ53.2, U32.4
A44: R149.2, SJ52.2, U32.3
A45: R148.2, SJ51.2, U32.2
A46: R147.2, SJ50.2, U32.1
A47: R152.2, SJ55.2, U32.24
A48: R170.2, SJ61.2, U36.5
A49: R169.2, SJ60.2, U36.4
A50: R168.2, SJ59.2, U36.3
A51: R167.2, SJ58.2, U36.2
A52: R166.2, SJ57.2, U36.1
A53: R171.2, SJ62.2, U36.24
A54: R189.2, SJ68.2, U40.5
A55: R188.2, SJ67.2, U40.4
A56: R187.2, SJ66.2, U40.3
A57: R186.2, SJ65.2, U40.2
A58: R185.2, SJ64.2, U40.1
A59: R190.2, SJ69.2, U40.24
A60: R208.2, SJ75.2, U44.5
A61: R207.2, SJ74.2, U44.4
A62: R206.2, SJ73.2, U44.3
A63: R205.2, SJ72.2, U44.2
A64: R204.2, SJ71.2, U44.1
A65: R209.2, SJ76.2, U44.24
A66: R227.2, SJ82.2, U48.5
A67: R226.2, SJ81.2, U48.4
A68: R225.2, SJ80.2, U48.3
A69: R224.2, SJ79.2, U48.2
A70: R223.2, SJ78.2, U48.1
A71: R228.2, SJ83.2, U48.24
A72: R246.2, SJ89.2, U52.5
A73: R245.2, SJ88.2, U52.4
A74: R244.2, SJ87.2, U52.3
A75: R243.2, SJ86.2, U52.2
A76: R242.2, SJ85.2, U52.1
A77: R247.2, SJ90.2, U52.24
A78: R265.2, SJ96.2, U56.5
A79: R264.2, SJ95.2, U56.4
A80: R263.2, SJ94.2, U56.3
A81: R262.2, SJ93.2, U56.2
A82: R261.2, SJ92.2, U56.1
A83: R266.2, SJ97.2, U56.24
A84: R284.2, SJ103.2, U60.5
A85: R283.2, SJ102.2, U60.4
A86: R282.2, SJ101.2, U60.3
A87: R281.2, SJ100.2, U60.2
A88: R280.2, SJ99.2, U60.1
A89: R285.2, SJ104.2, U60.24
A90: R303.2, SJ110.2, U64.5
A91: R302.2, SJ109.2, U64.4
A92: R301.2, SJ108.2, U64.3
A93: R300.2, SJ107.2, U64.2
A94: R299.2, SJ106.2, U64.1
A95: R304.2, SJ111.2, U64.24
A96: R322.2, SJ117.2, U68.5
A97: R321.2, SJ116.2, U68.4
A98: R320.2, SJ115.2, U68.3
A99: R319.2, SJ114.2, U68.2
A100: R318.2, SJ113.2, U68.1
A101: R323.2, SJ118.2, U68.24
A102: R341.2, SJ124.2, U72.5
A103: R340.2, SJ123.2, U72.4
A104: R339.2, SJ122.2, U72.3
A105: R338.2, SJ121.2, U72.2
A106: R337.2, SJ120.2, U72.1
A107: R342.2, SJ125.2, U72.24
A108: R360.2, SJ131.2, U76.5
A109: R359.2, SJ130.2, U76.4
A110: R358.2, SJ129.2, U76.3
A111: R357.2, SJ128.2, U76.2
A112: R356.2, SJ127.2, U76.1
A113: R361.2, SJ132.2, U76.24
A114: R379.2, SJ138.2, U80.5
A115: R378.2, SJ137.2, U80.4
A116: R377.2, SJ136.2, U80.3
A117: R376.2, SJ135.2, U80.2
A118: R375.2, SJ134.2, U80.1
A119: R380.2, SJ139.2, U80.24
A120: R398.2, SJ145.2, U84.5
A121: R397.2, SJ144.2, U84.4
A122: R396.2, SJ143.2, U84.3
A123: R395.2, SJ142.2, U84.2
A124: R394.2, SJ141.2, U84.1
A125: R399.2, SJ146.2, U84.24
A126: R417.2, SJ152.2, U88.5
A127: R416.2, SJ151.2, U88.4
A128: R415.2, SJ150.2, U88.3
A129: R414.2, SJ149.2, U88.2
A130: R413.2, SJ148.2, U88.1
A131: R418.2, SJ153.2, U88.24
A132: R436.2, SJ159.2, U92.5
A133: R435.2, SJ158.2, U92.4
A134: R434.2, SJ157.2, U92.3
A135: R433.2, SJ156.2, U92.2
A136: R432.2, SJ155.2, U92.1
A137: R437.2, SJ160.2, U92.24
A138: R455.2, SJ166.2, U96.5
A139: R454.2, SJ165.2, U96.4
A140: R453.2, SJ164.2, U96.3
A141: R452.2, SJ163.2, U96.2
A142: R451.2, SJ162.2, U96.1
A143: R456.2, SJ167.2, U96.24
A144: R474.2, SJ173.2, U100.5
A145: R473.2, SJ172.2, U100.4
A146: R472.2, SJ171.2, U100.3
A147: R471.2, SJ170.2, U100.2
A148: R470.2, SJ169.2, U100.1
A149: R475.2, SJ174.2, U100.24
A150: R493.2, SJ180.2, U104.5
A151: R492.2, SJ179.2, U104.4
A152: R491.2, SJ178.2, U104.3
A153: R490.2, SJ177.2, U104.2
A154: R489.2, SJ176.2, U104.1
A155: R494.2, SJ181.2, U104.24
A156: R512.2, SJ187.2, U108.5
A157: R511.2, SJ186.2, U108.4
A158: R510.2, SJ185.2, U108.3
A159: R509.2, SJ184.2, U108.2
A160: R508.2, SJ183.2, U108.1
A161: R513.2, SJ188.2, U108.24
A162: R531.2, SJ194.2, U112.5
A163: R530.2, SJ193.2, U112.4
A164: R529.2, SJ192.2, U112.3
A165: R528.2, SJ191.2, U112.2
A166: R527.2, SJ190.2, U112.1
A167: R532.2, SJ195.2, U112.24
A168: R550.2, SJ201.2, U116.5
A169: R549.2, SJ200.2, U116.4
A170: R548.2, SJ199.2, U116.3
A171: R547.2, SJ198.2, U116.2
A172: R546.2, SJ197.2, U116.1
A173: R551.2, SJ202.2, U116.24
A174: R569.2, SJ208.2, U120.5
A175: R568.2, SJ207.2, U120.4
A176: R567.2, SJ206.2, U120.3
A177: R566.2, SJ205.2, U120.2
A178: R565.2, SJ204.2, U120.1
A179: R570.2, SJ209.2, U120.24
A180: R588.2, SJ215.2, U124.5
A181: R587.2, SJ214.2, U124.4
A182: R586.2, SJ213.2, U124.3
A183: R585.2, SJ212.2, U124.2
A184: R584.2, SJ211.2, U124.1
A185: R589.2, SJ216.2, U124.24
A186: R607.2, SJ222.2, U128.5
A187: R606.2, SJ221.2, U128.4
A188: R605.2, SJ220.2, U128.3
A189: R604.2, SJ219.2, U128.2
A190: R603.2, SJ218.2, U128.1
A191: R608.2, SJ223.2, U128.24
CH0: JP1.3, R13.1, U1.6
CH1: JP2.3, R12.1, U1.7
CH2: JP3.3, R11.1, U1.8
CH3: JP4.3, R10.1, U1.9
CH4: JP5.3, R9.1, U1.10
CH5: JP6.3, R8.1, U1.11
CH6: JP7.3, R7.1, U1.12
CH7: JP8.3, R6.1, U1.13
CH8: JP10.3, R32.1, U8.6
CH9: JP11.3, R31.1, U8.7
CH10: JP12.3, R30.1, U8.8
CH11: JP13.3, R29.1, U8.9
CH12: JP14.3, R28.1, U8.10
CH13: JP15.3, R27.1, U8.11
CH14: JP16.3, R26.1, U8.12
CH15: JP17.3, R25.1, U8.13
CH16: JP19.3, R51.1, U12.6
CH17: JP20.3, R50.1, U12.7
CH18: JP21.3, R49.1, U12.8
CH19: JP22.3, R48.1, U12.9
CH20: JP23.3, R47.1, U12.10
CH21: JP24.3, R46.1, U12.11
CH22: JP25.3, R45.1, U12.12
CH23: JP26.3, R44.1, U12.13
CH24: JP28.3, R70.1, U16.6
CH25: JP29.3, R69.1, U16.7
CH26: JP30.3, R68.1, U16.8
CH27: JP31.3, R67.1, U16.9
CH28: JP32.3, R66.1, U16.10
CH29: JP33.3, R65.1, U16.11
CH30: JP34.3, R64.1, U16.12
CH31: JP35.3, R63.1, U16.13
CH32: JP37.3, R89.1, U20.6
CH33: JP38.3, R88.1, U20.7
CH34: JP39.3, R87.1, U20.8
CH35: JP40.3, R86.1, U20.9
CH36: JP41.3, R85.1, U20.10
CH37: JP42.3, R84.1, U20.11
CH38: JP43.3, R83.1, U20.12
CH39: JP44.3, R82.1, U20.13
CH40: JP46.3, R108.1, U24.6
CH41: JP47.3, R107.1, U24.7
CH42: JP48.3, R106.1, U24.8
CH43: JP49.3, R105.1, U24.9
CH44: JP50.3, R104.1, U24.10
CH45: JP51.3, R103.1, U24.11
CH46: JP52.3, R102.1, U24.12
CH47: JP53.3, R101.1, U24.13
CH48: JP55.3, R127.1, U28.6
CH49: JP56.3, R126.1, U28.7
CH50: JP57.3, R125.1, U28.8
CH51: JP58.3, R124.1, U28.9
CH52: JP59.3, R123.1, U28.10
CH53: JP60.3, R122.1, U28.11
CH54: JP61.3, R121.1, U28.12
CH55: JP62.3, R120.1, U28.13
CH56: JP64.3, R146.1, U32.6
CH57: JP65.3, R145.1, U32.7
CH58: JP66.3, R144.1, U32.8
CH59: JP67.3, R143.1, U32.9
CH60: JP68.3, R142.1, U32.10
CH61: JP69.3, R141.1, U32.11
CH62: JP70.3, R140.1, U32.12
CH63: JP71.3, R139.1, U32.13
CH64: JP73.3, R165.1, U36.6
CH65: JP74.3, R164.1, U36.7
CH66: JP75.3, R163.1, U36.8
CH67: JP76.3, R162.1, U36.9
CH68: JP77.3, R161.1, U36.10
CH69: JP78.3, R160.1, U36.11
CH70: JP79.3, R159.1, U36.12
CH71: JP80.3, R158.1, U36.13
CH72: JP82.3, R184.1, U40.6
CH73: JP83.3, R183.1, U40.7
CH74: JP84.3, R182.1, U40.8
CH75: JP85.3, R181.1, U40.9
CH76: JP86.3, R180.1, U40.10
CH77: JP87.3, R179.1, U40.11
CH78: JP88.3, R178.1, U40.12
CH79: JP89.3, R177.1, U40.13
CH80: JP91.3, R203.1, U44.6
CH81: JP92.3, R202.1, U44.7
CH82: JP93.3, R201.1, U44.8
CH83: JP94.3, R200.1, U44.9
CH84: JP95.3, R199.1, U44.10
CH85: JP96.3, R198.1, U44.11
CH86: JP97.3, R197.1, U44.12
CH87: JP98.3, R196.1, U44.13
CH88: JP100.3, R222.1, U48.6
CH89: JP101.3, R221.1, U48.7
CH90: JP102.3, R220.1, U48.8
CH91: JP103.3, R219.1, U48.9
CH92: JP104.3, R218.1, U48.10
CH93: JP105.3, R217.1, U48.11
CH94: JP106.3, R216.1, U48.12
CH95: JP107.3, R215.1, U48.13
CH96: JP109.3, R241.1, U52.6
CH97: JP110.3, R240.1, U52.7
CH98: JP111.3, R239.1, U52.8
CH99: JP112.3, R238.1, U52.9
CH100: JP113.3, R237.1, U52.10
CH101: JP114.3, R236.1, U52.11
CH102: JP115.3, R235.1, U52.12
CH103: JP116.3, R234.1, U52.13
CH104: JP118.3, R260.1, U56.6
CH105: JP119.3, R259.1, U56.7
CH106: JP120.3, R258.1, U56.8
CH107: JP121.3, R257.1, U56.9
CH108: JP122.3, R256.1, U56.10
CH109: JP123.3, R255.1, U56.11
CH110: JP124.3, R254.1, U56.12
CH111: JP125.3, R253.1, U56.13
CH112: JP127.3, R279.1, U60.6
CH113: JP128.3, R278.1, U60.7
CH114: JP129.3, R277.1, U60.8
CH115: JP130.3, R276.1, U60.9
CH116: JP131.3, R275.1, U60.10
CH117: JP132.3, R274.1, U60.11
CH118: JP133.3, R273.1, U60.12
CH119: JP134.3, R272.1, U60.13
CH120: JP136.3, R298.1, U64.6
CH121: JP137.3, R297.1, U64.7
CH122: JP138.3, R296.1, U64.8
CH123: JP139.3, R295.1, U64.9
CH124: JP140.3, R294.1, U64.10
CH125: JP141.3, R293.1, U64.11
CH126: JP142.3, R292.1, U64.12
CH127: JP143.3, R291.1, U64.13
CH128: JP145.3, R317.1, U68.6
CH129: JP146.3, R316.1, U68.7
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

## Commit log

2014-08-06 Add version info
    [servo_board.brd, servo_board.sch]
2014-08-06 Touch up silk, resistor placement
    [servo_board.brd, servo_board.sch]
2014-08-06 Increased length of board by 100th
    [servo_board.brd]
2014-08-06 Skootch resistors out of keepout region.
    [servo_board.brd]
2014-08-07 Move resistors and traces out of restrict zone
    [servo_board.brd]
2014-08-08 Incorporate review changes
    [servo_board.brd, servo_board.sch]
2014-08-11 Add fids
    [servo_board.brd, servo_board.sch]
2014-08-12 Fix fids, remove weird name
    [servo_board.brd, servo_board.sch]
2014-09-24 Added DCIN pin Corrected Header footprint Renamed board and files Cleaned up dimensions and added units Added VSYS -> VIN circuit Added DNP to pullup resistors
    [PWM_Block.brd, PWM_Block.sch]
2014-10-16 Rev to 10. Fix gnd and pwr, text
    [PWM_Block.brd, PWM_Block.sch]
2014-10-17 Touch up packages, silk for reds
    [PWM_Block.brd, PWM_Block.sch]
2014-10-17 Ready for reds Thicken VSYS->VIN trace Fix a stray ground thermal on PCA9306 No known to-do items
    [PWM_Block.brd, PWM_Block.sch]
2014-10-22 created v10 panels
    [PWM_Block-GiantPanel-v10.brd, PWM_Block-Panel-v10.brd]
2015-04-01 Updating README and directory names
    [PWM_Block-GiantPanel-v10.brd, PWM_Block-Panel-v10.brd]

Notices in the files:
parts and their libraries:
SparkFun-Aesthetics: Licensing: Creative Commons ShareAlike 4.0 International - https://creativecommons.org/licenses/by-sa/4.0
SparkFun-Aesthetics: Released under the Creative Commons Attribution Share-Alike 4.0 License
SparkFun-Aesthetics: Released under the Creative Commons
